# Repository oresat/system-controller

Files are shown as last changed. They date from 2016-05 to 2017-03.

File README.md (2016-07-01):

# OreSat "System controller" Board
<p align="center">
  
</p>
## Overview

The System Controller (SC) is part of the sputnik capstone project and is a robust module that is a vital piece of the avionics stack for the cubesat. It is tasked with performing the most critical job of all: monitoring the well-being of the stack and power cycling modules when [Single-Event Upsets](https://en.wikipedia.org/wiki/Single_event_upset) happen. At the heart of the module will be a radiation hardened microcontroller that communicates with the Low Gain Radio and Payload via UART. There are power switches with circuit breakers ("efuses") connected to the microcontroller that allow it to control the flow of power to all of the other systems/modules on the CubeSat.  
Low level diagram of System Controller  

## Main Topics
[Parts Selection](https://github.com/oresat/system-controller/blob/master/docs/PartsSelection.md)  
[Bill of Materials](https://github.com/oresat/system-controller/blob/master/docs/BOM_SC.xls)  
[Eagle Schematic](https://github.com/oresat/system-controller/blob/master/eagle/system-controller.sch)    
[Eagle Layout](https://github.com/oresat/system-controller/blob/master/eagle/system-controller.brd)    
[Test Plan](https://github.com/oresat/low-gain-radio/blob/master/docs/Test_Plan_Sputnik_Capstone.md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)   

## Contents

datasheets - datasheets for components used

docs - documentation

eagle - contains Schematic and PCB layout for the System Controller

firmware - contains firmware for the System Controller and tools for compiling/debugging

## Project team

Industry Sponsor: Andrew Greenberg (adg@ece.pdx.edu)

Faculty Advisor: Dr. Christof Teuscher (teuscher@pdx.edu)

* Capstone Team

    * William Harrington (wrh2@pdx.edu)

    * Shan Quinney (quinney@pdx.edu)

    * Jake Heath (jakeheath@gmail.com)

    * Mike Mathis (mdmathis@gmail.com)

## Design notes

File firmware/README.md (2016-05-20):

# System Controller Firmware

This folder contains the firmware for the system controller.
The system controller contains an [Atmega128](http://www.atmel.com/devices/ATMEGA128.aspx) which is a microcontroller developed by [Atmel](http://www.atmel.com/).
The microcontroller itself is composed of an [AVR based architecture](https://en.wikipedia.org/wiki/Atmel_AVR) which was developed by Atmel.
It is for this reason that the tool chain for the system controller and low gain radio are completely different.
Furthermore, the Atmega128 is not going to be used for actual flight/deployment in space. Instead, there is a [radiation-hardened version](http://www.atmel.com/devices/ATmegaS128.aspx) of it that we plan to use.
As far as programming is concerned, there is no difference between this version and the Atmega128.

## Dependencies

[avrdude](http://www.nongnu.org/avrdude/)

## Caveats

The Makefile assumes an Atmel AVR JTAGICE3 is being used with an Atmega128.

## Fuse bits

In order for the clock to function properly the currect fuse bits need to be set. This can be done in avrdude by including the following command line argument:

	-U lfuse:w:0xc0:m -U hfuse:w:0x89:m -U efuse:w:0xff:m

The CKOPT bit is set so that the crystal receives more power so that it can be detected reliably at 8MHz. If CKOPT is not set, the clock from the crystal wont be strong enough.

## Example usage

* To compile

    > make

* To complie and write to Atmega128

    > make load

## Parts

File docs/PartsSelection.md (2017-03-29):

# Parts Selection for System Controller
**Table of Contents**	
* [Microcontroller](https://github.com/oresat/system-controller/blob/master/docs/PartsSelection.md#u1-atmel-atmega128)	
* [LDO](https://github.com/oresat/system-controller/blob/master/docs/PartsSelection.md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)	
* [Optical Isolator](https://github.com/oresat/system-controller/blob/master/docs/PartsSelection.md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)		
* [Power Management (eFuse)](https://github.com/oresat/system-controller/blob/master/docs/PartsSelection.md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) 	
* [8:1 Multiplexer](https://github.com/oresat/system-controller/blob/master/docs/PartsSelection.md#u15-silicon-labs-ts4100itq1633)		
* [SuperCap](https://github.com/oresat/system-controller/blob/master/docs/PartsSelection.md#c1-elna-america-dsk-3r3h224u-hl) 	
* [Schottky Diode](https://github.com/oresat/system-controller/blob/master/docs/PartsSelection.md#d1-d2-d3-vishay-ssc53l-e357t)		
* [8MHz Crystal](https://github.com/oresat/system-controller/blob/master/docs/PartsSelection.md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)		
* [MOSFETs](https://github.com/oresat/system-controller/blob/master/docs/PartsSelection.md#mosfets)		
* [Connectors](https://github.com/oresat/system-controller/blob/master/docs/PartsSelection.md#connectors)				
* [LEDs](https://github.com/oresat/system-controller/blob/master/docs/PartsSelection.md#leds)	
* [Capacitors](https://github.com/oresat/system-controller/blob/master/docs/PartsSelection.md#capacitors)	
* [Resistors](https://github.com/oresat/system-controller/blob/master/docs/PartsSelection.md#resistors)

Format note  

#### Format note  
Eagle Reference, Manufacturer, Manufacturer's Part Number  
Vendor  
Vendor Part No  
Datasheet  
Reasons  
Rad-hard Analogue 

#### U1 Atmel ATMega128  
Description: Microcontroller 8BIT 128KB FLASH 	
Vendor: Digi-Key 	
Vendor Part No.: ATMEGA128L-8AU 			
[Datasheet](http://www.atmel.com/images/doc2467.pdf)  
Reasons: The ATMega128 comes in both a radiation hardened and non-hardened version. This gives us the ability to fabricate and test the full board for functionality using the cheaper non-hardened version before purchasing the more expensive radiation tolerant part. An additional benefit is that the ATMega128 has a large community of users with access to open source code and documentation. This will help us bring the chip up quickly.
Rad-hard Analogue: ATmegaS128		
[Datasheet](http://aerosupport.atmel.com/Atmel/doc41036.pdf)  

#### U2 Texas Instruments LP5907MFX-3.0/NOPB 
Description:  MCU LDO  
Vendor: Digi-Key  
Vendor Part No.: 296-40357-1-ND		
[Datasheet](http://www.ti.com/lit/ds/symlink/lp5907.pdf)  
Reasons: This is a replacement for our original choice - the Skyworks AAT3215, which is not available through digikey. This one comes in the same package and it also has a functionally equivalent pin-out to the AAT3215. The input voltage range is 2.2V to 5.5 V and the drop out voltage is given at 120 mV.	
Rad-Hard Analogue: ISL75051SEH	
[Datasheet](http://www.intersil.com/content/dam/Intersil/documents/isl7/isl75051seh.pdf)	
Reasons: This chip is rated with a low drop out of 65mV at 1A (225mV at 3A). The IC operates over a voltage range of 2.2V to 6.0V and can provide output voltages between 0.8V and 5V. The output voltage is set using an external resistive voltage divider.

#### U3, U4, U5, U6 Broadcom Limited ACPL-M61L-000E
Description: Optoisolator 3.75KV PUSH PULL 	
Vendor: Digi-Key  
Vendor Part No.: 516-2169-5-ND		
[Datasheet](http://www.avagotech.com/docs/AV02-2150EN)  
Reasons: This IC is less complex than other comparable products. The chip can be powered from a 3.0V supply and features a low 1.6mA input current. The temperature range exceeds requirements on the high end (-40C to 105C). As a note, the output is inverted.		
Rad-hard Analogue: Avago HCPL5431		
[Datasheet](http://www.avagotech.com/docs/AV02-3838EN)

#### U7, U8, U9, U10, U11, U12, U13, U14 Texas Instruments TPS25944LRVCR
Description: IC Power Management eFuse 		
Vendor: Digi-Key  
Vendor Part No.: 296-42152-1-ND		
[Datasheet](http://www.ti.com/lit/ds/symlink/tps25944a.pdf)		
Reasons: This IC offered the most complete solution compared to the competition. The chip can be powered from a 3.0V supply (has an operating voltage range of 2.7V to 18V). It has a current limiting feature, which is set by an external resistor. It alows for current monitoring, undervoltage protection, overvoltage protection, and the slew rate is adjustable by use of an external capacitor.		
Rad-hard Analogue: Intersil ISL706		
[Datasheet](https://www.intersil.com/content/dam/Intersil/documents/isl7/isl705arh-05brh-05crh-05aeh-05beh-05ceh-06arh-06brh-06crh-06aeh-06beh-06ceh.pdf)

#### U15 Silicon Labs TS4100ITQ1633
Description: 8:1 Mux	/ Analog Switch
Vendor: Digi-Key  
Vendor Part No.: 336-3600-ND	
[Datasheet](http://www.silabs.com/Support%20Documents/TechnicalDocs/TS410x.pdf)		
Reasons: This chip could be considered generic as there were no specific reasons that it was chosen other than it can be powered from 3.0V and comes in a small 3 x 3 TQFN package.			
Rad-hard Analogue: ST M54HC4051		
[Datasheet](http://www2.st.com/content/ccc/resource/technical/document/datasheet/20/18/fe/5f/87/91/46/35/CD00270015.pdf/files/CD00270015.pdf/jcr:content/translations/en.CD002700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)

#### C1 Elna America DSK-3R3H224U-HL
Description: 220 mF SuperCap	
Vendor: Digi-Key  
Vendor Part No.: 604-1020-1-ND		
[Datasheet](http://media.digikey.com/pdf/Data%20Sheets/Elna%20America%20Inc/DS,DSK.pdf)		
Reasons:  The same capacitor was used on a previous PSAS board and proved to be reliable. This capacitor should supply at least half a minute of charge if the power system fails.	 
Rad-hard Analogue: N/A

#### D1, D2, D3 Vishay SSC53L-E3/57T
Description: Schottky Diode	
Vendor: Digi-Key  		
Vendor Part No.: SSC53L-E3/57TGICT-ND	
[Datasheet](https://www.vishay.com/docs/88885/ssc53l.pdf)	
Reasons: This Diode was chosen because it has a similar turn-on voltage to the radiation hardened version.	
Rad-Hard Analogue: ST 1N5819U:		
[Datasheet](http://www.st.com/st-web-ui/static/active/en/resource/technical/document/datasheet/CD00241480.pdf)		
Reasons: Low Turn-on voltage. 

#### X1 Abaracon LLC ABM3-8.000MHZ-D2Y-T 
Description:  8MHz +/- 20ppm Crystal    
Vendor: Digi-Key  
Vendor Part No.: 1535-10630-1-ND	
[Datasheet](http://www.abracon.com/Resonators/abm3.pdf)  
Reasons: This is a good valued crystal with decent ppm count (+/-20ppm).	
Rad-hard Analogue: Swept Crystal		
[Datasheet](http://statek.com/products/pdf/SWCX1%20Swept%20Crystal%20Rev%20B.pdf)	
Reasons: The swept crystal is recommended for harsh environments. 

#### MOSFETs
**Q3 Didoes Inc. DMN62D0U-13**		
Description: MOSFET N-CH 60V 0.38A		
Vendor: Digi-Key  
Vendor Part No.: DMN62D0U-13DICT-ND		
[Datasheet](http://www.diodes.com/_files/datasheets/DMN62D0U.pdf)	
Reasons: This MOSFET was chosen based on the threshold voltage range of 0.5V to 1V. This allows the capacitor in the hardware watchdog circuitry more time to discharge from the 3V rail to where the FET turns off. Note: It has been dificult to find a radiation hardened transistor with a similar threshhold voltage range. This could be critical to reproducing the watchdog timing.				
Rad-Hard Option: Intentional Rectifier IRHLUB770Z4	
[Datasheet](http://www.irf.com/product-info/datasheets/data/irhlub770z4.pdf) 		
Reasons: Lowest Threshold voltage of any rad-hard FET viewed. This one is between 1V and 2V.

**Q9, Q11 On Semi. DMN62D0U-13** 
Description: MOSFET P-CH 20V 3.2A SOT23		
Vendor: Digi-Key  
Vendor Part No.: NTR4101PT1HOSCT-ND		
[Datasheet](http://www.onsemi.com/pub_link/Collateral/NTR4101P-D.PDF)	
Reasons: Generic P-channel MOSFET. 	
Rad-hard Analogue: International Rectifier IRHYB597Z30CM	
[Datasheet](http://www.irf.com/product-info/datasheets/data/irhyb597z30cm.pdf)		
Reasons: This transistor should be considered generic.

**Q1, Q2, Q4, Q5, Q6, Q7, Q8, Q10 Diodes Inc. DMG6601LVT-7**     
Description: MOSFET, N/P pair     
Vendor: Digi-Key  
Vendor Part No.: DMG6601LVT-7DICT-ND 	  
[Datasheet](http://www.diodes.com/_files/datasheets/DMG6601LVT.pdf)  
Reasons: This chip has been used in a previous PSAS design and has proved to be reliable.	
Rad-hard Analogue: International Rectifier IRHLUC7670Z4			
[Datasheet](http://www.irf.com/product-info/datasheets/data/irhluc7670z4.pdf)
Reasons: This chip should be considered generic.

#### Connectors
**J1 CNC Tech 3220-10-0100-00** 
Description: JTAG Connector    
Vendor: Digi-Key  
Vendor Part No.: 1175-1627-ND   
[Datasheet](http://cnctech.us/pdfs/3220-XX-0100-00.pdf)  
Reasons: This is a generic JTAG connector.	
Rad-hard Analogue: N/A	

**CF1, CF2 Harwin Inc. M50-3202045**     
Description: 40-Pinout Header     
Vendor: Digi-Key  
Vendor Part No.: 952-1381-5-ND  	  
[Datasheet](https://cdn.harwin.com/pdfs/M50-320.pdf)  
Reasons: This is a design requirement for communication from the Cubesat and allows for a link between the LGR and System Controller.			
Rad-hard Analogue: N/A	

### LEDs
**LED1, LED2, LED3, LED4, LED5, LED6, LED7, LED8, LED13 Wurth Electronics, Inc. 150060GS75000**      
Description: Green LEDs    
Vendor: Digi-Key  
Vendor Part No.: 732-4971-1-ND 	
[Datasheet](http://katalog.we-online.de/led/datasheet/150060GS75000.pdf)  
Reasons: LED1 - LED8 are on the VCB0 - VCB7 lines and are functionally located between the output of the eFuse modules and the input of the 40 pin connector. LED13 is used to indicate 3.0V operation. They are placed at the front of the board for easy viewing and when on represent that the line of interest is working. These LEDs are for debugging only and will be removed before launch.			
Rad-hard Analogue: N/A	

**LED9, LED10, LED11, LED12 OSRAM Optp Semi. LA L296-Q2R2-1-Z**      
Description: Amber LEDs    
Vendor: Digi-Key  
Vendor Part No.: 475-2712-1-ND  
[Datasheet](http://media.digikey.com/pdf/Data%20Sheets/Osram%20PDFs/LS,LA,LO,LY_296.pdf)  
Reasons: Amber LEDs are used for error checks during debugging and are placed on the debugging lines for UART. They will also be removed before actual launch.	
Rad-hard Analogue: N/A	

### Capacitors

**C1, C6, C7, C9, C14, C20, C22, C23, C25, C29 Samsung CL10B105KP8NNNC**       
Description: 1µF ±10% 10V X7R Ceramic Capacitor SMD, MLCC 0603 
Vendor: Digi-Key  
Vendor Part No.: 1276-1946-1-ND  
[Datasheet](http://www.samsungsem.com/kr/support/product-search/mlcc/__icsFiles/afieldfile/2015/06/15/CL10B105KP8NNNC.pdf)  
Reasons: These capacitors are used as bypass caps. C1, C7, C9, C14, C20, C22, C25, and C29 are used on the eFuse ICs. C23 is found on the 8:1 Mux and C6 is on the LDO.	
Rad-hard Analogue: N/A	

**C2, C8, C11, C16, C21, C24, C26, C30 Samsung CL10C222GA8NNNC**       
Description: 2200pF ±2% 25V C0G, NP0 Ceramic Capacitor SMD, MLCC 0603
Vendor: Digi-Key  
Vendor Part No.: 1276-2239-1-ND		
[Datasheet](http://www.samsungsem.com/kr/support/product-search/mlcc/__icsFiles/afieldfile/2015/06/03/CL10C222GA8NNNC.pdf)  
Reasons: C2, C8, C11, C16, C21, C24, C26, and C30 are used on the TPS25944LRVCR eFuse IC's to set the ramp rate of output voltage.	
Rad-hard Analogue: N/A	

**C15, C17 Samsung CL10C090DB8NNNC**       
Description: 9pF ±0.5pF 50V C0G, NP0 Ceramic Capacitor SMD, MLCC 0603	
Vendor: Digi-Key  
Vendor Part No.: 1276-2143-1-ND		
[Datasheet](http://www.samsungsem.com/kr/support/product-search/mlcc/__icsFiles/afieldfile/2015/06/03/CL10C090DB8NNNC.pdf)  
Reasons: These caps compliment the 8MHz Crystal on the ATMega128 microcontroller.	
Rad-hard Analogue: N/A	

**C5 Samsung CL10A225KQ8NNNC**       
Description: 2.2µF ±10% 6.3V X5R Ceramic Capacitor SMD, MLCC 0603	
Vendor: Digi-Key  
Vendor Part No.: 1276-1183-1-ND		
[Datasheet](http://www.samsungsem.com/kr/support/product-search/mlcc/__icsFiles/afieldfile/2015/08/14/S_CL10A225KQ8NNNC.pdf)  
Reasons: C5 is used as a bypass capacitor on the LDO. 	
Rad-hard Analogue: N/A	

**C10 Samsung CL10A226KQ8NRNE**       
Description: 22µF ±10% 6.3V X5R Ceramic Capacitor SMD, MLCC 0603	
Vendor: Digi-Key  
Vendor Part No.: 1276-2867-2-ND		
[Datasheet](http://media.digikey.com/pdf/Data%20Sheets/Samsung%20PDFs/CL10A226KQ8NRNE_Spec.pdf)  
Reasons: This capacitor is used on the Hardware Watchdog as part of the RC timing circuit.	 
Rad-hard Analogue: N/A	

**C4 Kemet C0603C103J5RACTU**       
Description: 10000pF ±5% 50V X7R Ceramic Capacitor SMD, MLCC 0603	
Vendor: Digi-Key  
Vendor Part No.: 399-1092-1-ND	
[Datasheet](http://www.kemet.com/docfinder?Partnumber=C0603C103J5RACTU)  
Reasons: C4 is used as a bypass Cap on the AAT3215 LDO.	It is not used on the current LDO as that pin is a no connect.	
Rad-hard Analogue: N/A

**C12, C13, C18, C19, C27, C28, C31, C32 Kemet C0603C103J5RACTU**       
Description: 0.10µF ±5% 16V X7R Ceramic Capacitor SMD, MLCC 0603	
Vendor: Digi-Key  
Vendor Part No.: 399-1097-1-ND	
[Datasheet](http://www.kemet.com/Lists/ProductCatalog/Attachments/53/KEM_C1002_X7R_SMD.pdf)  
Reasons: C12, C13, C18, and C19 are used as bypass caps on the ATMega128 microcontroller. C27, C28, C31, and C32 are used as bypass caps on the optoisolators.	
Rad-hard Analogue: N/A	
#### Resistors

**R7	Samsung	RC1608F103CS**      
Description: RES SMD 10K OHM 1% 1/10W 0603				
Vendor: Digi-Key				  
Vendor Part No.: 1276-3485-1-N				 	
[Datasheet](http://media.digikey.com/pdf/Data%20Sheets/Samsung%20PDFs/RC_Series_ds.pdf)  
Reasons: This 10k resistor is used as a pull-up resistor on the LDO.		
Rad-hard Analogue: N/A	    

**RIMON1, RIMON2, RIMON3, RIMON4, RIMON5, RIMON6, RIMON7, RIMON8 Samsung RC1608F3012CS**      
Description: RES SMD 30.1K OHM 1% 1/10W 0603				
Vendor: Digi-Key			  
Vendor Part No.: 1276-4787-1-N				 	
[Datasheet](http://media.digikey.com/pdf/Data%20Sheets/Samsung%20PDFs/RC_Series_ds.pdf)  
Reasons: These resistors are configured as current monitoring resistors for the eFuse circuitry. They allow the microcontroller to monitor the amount of current through the output of each eFuse IC.	
Rad-hard Analogue: N/A	

**R18 Samsung RC1608F474CS**      
Description: RES SMD 470K OHM 1% 1/10W 0603				
Vendor: Digi-Key			  
Vendor Part No.: 1276-4902-1-ND 				 
[Datasheet](http://media.digikey.com/pdf/Data%20Sheets/Samsung%20PDFs/RC_Series_ds.pdf)  
Reasons: This resistor is part of the RC timing circuit in the hardware watchdog. It compliments capacitor C10 for this purpose.
Rad-hard Analogue: N/A	

**R14, R15, R16, R19, R25, R54, R60, R61, R70, R72, R74  Samsung RC0603FR-071KL**      
Description: RES SMD 390 OHM 0.1% 1/16W 060			   
Vendor: Digi-Key				  
Vendor Part No.: 1276-4610-1-N				 	
[Datasheet](http://media.digikey.com/pdf/Data%20Sheets/Samsung%20PDFs/RC_Series_ds.pdf)  
Reasons: R25 is used as a pull-up resistor for the !RESET line on the ATMega128. R54, R61, R70, and R74 are used as pull-up resistors on the Optoisolators. R60 and R72 are on the output lines of the optoisolators and act as pull down resistors when the output is low. RN14, RN15, RN16, and RN19 are used as part of the hardware watchdog voltage divide network. 	
Rad-hard Analogue: N/A	

**R4, R11, R22, R29, R43, R49, R57, R67 Yageo RC1608F472CS**     
Description: RES SMD 4.7K OHM 1% 1/10W 060				 
Vendor: Digi-Key				  
Vendor Part No.: 1276-3502-1-N				 	
[Datasheet](http://media.digikey.com/pdf/Data%20Sheets/Samsung%20PDFs/RC_Series_ds.pdf)  
Reasons: These resistors are part of the external biasing of the eFuse section P/N MOSFET network.	
Rad-hard Analogue: N/A	

**R2, R9, R20, R27, R41, R47, R55, R65 Samsung RC1608F9312CS**      
Description: RES SMD 93.1K OHM 1% 1/10W 060			 
Vendor: Digi-Key				  
Vendor Part No.: 1276-4837-1-ND 				 
[Datasheet](http://media.digikey.com/pdf/Data%20Sheets/Samsung%20PDFs/RC_Series_ds.pdf)  
Reasons: Used as under voltage lock out for the eFuse IC's. This is part of a voltage divider network that sets the voltage at the EN/UVLO pin to 3V.	
Rad-hard Analogue: N/A	

**R3, R10, R21, R28, R42, R48, R52, R56, R63, R66, R71, R75, R76 Samsung RC1608F102CS**      
Description: RES SMD 1K OHM 1% 1/10W 0603		
Vendor: Digi-Key		 
Vendor Part No.: 1276-3484-1-ND				
[Datasheet](http://media.digikey.com/pdf/Data%20Sheets/Samsung%20PDFs/RC_Series_ds.pdf)  
Reasons:  R52, R63, R71, and R75 are used as current limiting resistors on the Amber LEDs. R3, R10, R21, R28, R42, R48, R56, R66, and R76 are used as current limiting resistors on the Green LEDs.	
Rad-hard Analogue: N/A	

**R1, R5, R6, R8, R12, R13, R17, R23, R24, R26, R30, R31, R32, R33, R34, R35, R36, R37, R38, R39, R40, R44, R45, R46, R50, R51, R53, R58, R59, R62, R64, R68, R69, R73, RILIM1, RILIM2, RILIM3, RILIM4, RILIM5, RILIM6, RILIM7, RILIM8 Samsung RC1608F473CS**      
Description: RES SMD 47K OHM 1% 1/10W 0603		
Vendor: Digi-Key		 
Vendor Part No.: 1276-4808-1-ND 			
[Datasheet](http://media.digikey.com/pdf/Data%20Sheets/Samsung%20PDFs/RC_Series_ds.pdf)  
Reasons: R5, R12, R23, R30, R44, R50, R58, and R68 are part of the voltage divider network that sets the UVLO voltage on the eFues. R1, R5, R8, R12, R17, R23, R26, R30, R40, R44, R46, R50, R53, and R64 are used as part of the bias on the eFuse P/N MOSFET network. R32, R33, R34, R35, R36, R37, R38, R39 are used as pull up resistors on the VCB0-VCB7_FLT lines. RILIM0, RILIM1, RILIM2, RILIM3, RILIM4, RILIM5, RILIM6, RILIM7 are used to limit the current through the eFuse to 1.9A.	
Rad-hard Analogue: N/A

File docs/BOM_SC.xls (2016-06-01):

Bill Of Materials for PSAS System Controller (SC)
source file: system-controller.sch
Variant: NA
PCB version 1.0
BOM revision 0 |  |  | P/DNP = | Place/Do Not Place (DNP is for final production boards)
Last Modified: 2016.04.14 |  |  | Generic = | Any generic part with the same characteristics are OK (e.g., bypass cap)
Cnt | Part References | Manf | PN | P/DNP | Desc | Vendor | Vendor-PN | Generic | Price/Part | Extended
1 | J1 | CNC Tech | 3220-10-0100-00 |  | JTAG PIN HEADER 2x5 This is one of the (smaller) ARM standard JTAG connectors. | digikey | 1175-1627-ND | Y | 0.48 | 2.4
8 | C12, C13, C18, C19, C27, C28, C31, C32 | Kemet | C0603C104J4RACTU |  | 0.10µF ±5% 16V X7R Ceramic Capacitor SMD, MLCC 0603 | digikey | 399-1097-1-ND | Y | 0.0432 | 2.16
1 | R7 | Samsung | RC1608F103CS |  | RES SMD 10K OHM 1% 1/10W 0603 | digikey | 1276-3485-1-ND | Y | 0.014 | 0.14
1 | C4 | Kemet | C0603C103J5RACTU |  | 10000pF ±5% 50V X7R Ceramic Capacitor SMD, MLCC 0603 | digikey | 399-1092-1-ND | Y | 0.036 | 0.36
10 | C1, C6, C7, C9, C14, C20, C22, C23, C25, C29 | Samsung | CL10B105KP8NNNC |  | 1µF ±10% 10V X7R Ceramic Capacitor SMD, MLCC 0603 | digikey | 1276-1946-1-ND | Y | 0.0222 | 1.11
8 | C2, C8, C11, C16, C21, C24, C26, C30 | Samaung | CL10C222GA8NNNC |  | 2200pF ±2% 25V C0G, NP0 Ceramic Capacitor SMD, MLCC 0603 | digikey | 1276-2239-1-ND | Y | 0.0806 | 4.03
1 | C5 | Samsung | CL10A225KQ8NNNC |  | 2.2µF ±10% 6.3V X5R Ceramic Capacitor SMD, MLCC 0603 | digikey | 1276-1183-1-ND | Y | 0.087 | 0.87
1 | C10 | Kemet | CL10A226KQ8NRNE |  | 22µF ±10% 6.3V X5R Ceramic Capacitor SMD, MLCC 0603 | digikey | 1276-2867-2-ND | Y | 0.288 | 2.88
8 | RIMON0, RIMON1, RIMON2, RIMON3, RIMON4, RIMON5, RIMON6, RIMON7 | Samsung | RC1608F3012CS |  | RES SMD 30.1K OHM 1% 1/10W 0603 | digikey | 1276-4787-1-ND | Y | 0.0078 | 0.39
9 | R14, R15, R16, R19, R25, R54,, R61, R70, R74 | TE | RC1608F391CS |  | RES SMD 390 OHM 0.1% 1/16W 0603 | digikey | 1276-4610-1-ND | Y | 0.0078 | 0.39
8 | R4, R11, R22, R29, R43, R49, R57, R67 | Samsung | RC1608F472CS |  | RES SMD 4.7K OHM 1% 1/10W 0603 | digikey | 1276-3502-1-ND | Y | 0.0078 | 0.39
1 | R18 | Samsung | RC1608F474CS |  | RES SMD 470K OHM 1% 1/10W 0603 | digikey | 1276-4902-1-ND | Y | 0.014 | 0.14
42 | R1, R5, R6, R8, R12, R13, R17, R23, R24, R26, R30, R31, R32, R33, R34, R35, R36, R37, R38, R39, R40, R44, R45, R46, R50, R51, R53, R58, R59, R62, R64, R68, R69, R73, RILIM1, RILIM2, RILIM3, RILIM4, RILIM5, RILIM6, RILIM7, RILIM8 | Samsung | RC1608F473CS |  | RES SMD 47K OHM 1% 1/10W 0603 | digikey | 1276-4808-1-ND | Y | 0.0057 | 1.14
1 | X1 | Abracon LLC | ABM3-8.000MHZ-D2Y-T |  | 8MHz ±20ppm Crystal 18pF 140 Ohm 2-SMD | digikey | 535-10630-1-ND | Y | 0.69 | 3.45
8 | R2, R9, R20, R27, R41, R47, R55, R65 | Samsung | 1276-4837-1-ND |  | RES SMD 93.1K OHM 1% 1/10W 0603 | digikey | 1276-4837-1-ND | Y | 0.0078 | 0.39
2 | C15, C17 | Samsung | CL10C090DB8NNNC |  | 9pF ±0.5pF 50V C0G, NP0 Ceramic Capacitor SMD, MLCC 0603 | digikey | 1276-2143-1-ND | Y | 0.037 | 0.37
1 | U2 | Texas Instruments | LP5907MFX-3.0/NOPB |  | IC REG LDO 3V 0.25A SOT23-5 | digikey | 296-40357-1-ND | Y | 0.488 | 4.88
4 | U3, U4, U5, U6 | Broadcom | ACPL-M61L-000E |  | OPTOISO 3.75KV PUSH PULL 5SO | digikey | 516-2169-5-ND | Y | 1.7228 | 43.07
1 | C1 | Elna America | DSK-3R3H224U-HL |  | CAP 220MF -20% +80% 3.3V SMD | digikey | 604-1020-1-ND | Y | 1.426 | 14.26
13 | R3, R10, R21, R28, R42, R48, R52, R56, R63, R66, R71, R75, R76 | Samsung | RC1608F102CS | DNP | RES SMD 1K OHM 1% 1/10W 0603 | digikey | 1276-3484-1-ND | Y | 0.0078 | 0.39
4 | LED8, LED9, LED10, LED11 | OSRAM Op | LA L296-Q2R2-1-Z | DNP | LED AMBER DIFFUSED 0603 SMD | digikey | 475-2712-1-ND | Y | 0.083 | 1.66
8 | LED0, LED1, LED2, LED3, LED4, LED5, LED6, LED7, LED13 | Wurth Electronics | 150060GS75000 | DNP | LED GREEN CLEAR 0603 SMD | digikey | 732-4971-1-ND | Y | 0.21 | 10.5
2 | Q9, Q11 | ON Semic | NTR4101PT1H |  | MOSFET P-CH 20V 3.2A SOT23 | digikey | NTR4101PT1HOSCT-ND | Y | 0.346 | 3.46
1 | Q3 | Diodes Inc, | DMN62D0U-13 |  | MOSFET N-CH 60V 0.38A | digikey | DMN62D0U-13DICT-ND | Y | 0.255 | 2.55
1 | U1 | Atmel | ATMEGA128-16AUR |  | MICROCONTROLLER IC MCU 8BIT 128KB FLASH 64TQFP | digikey | ATMEGA128-16AURCT-ND | N | 16.05 | 80.25
8 | Q1, Q2, Q4, Q5, Q6, Q7, Q8, Q10 | Diodes Inc. | DMG6601LVT-7 |  | MOSFET N/P-CH 30V 26TSOT | digikey | DMG6601LVT-7DICT-ND | N | 0.283 | 8.49
2 | CF1, CF2 | Harwin Inc. | M50-3202045 |  | CONN RCPT 1.27MM T/H R/A 40POS (40 pin header) | digikey | 952-1381-5-ND | N | 5.126 | 51.26
3 | D1, D2, D3 | Vishay | SSC53L-E3/57T |  | DIODE SCHOTTKY 30V 5A DO214AB | digikey | SSC53L-E3/57TGICT-ND | N | 0.534 | 6.408
8 | U7, U8, U9, U10, U11, U12, U13, U14 | Texas Instruments | TPS25944LRVCR |  | IC PWR MGMT EFUSE 2.7-18V 20WQFN | digikey | 296-42152-1-ND | N | 1.843 | 55.29
1 | U15 | Silicon Labs | TS4100ITQ1633 |  | 80 RON ANALOG SWITCH/MULTIPLEXE | digikey | 336-3600-ND | N | 1.22 | 4.88
2 |  |  |  |  |  |  |  |  |  | 307.958

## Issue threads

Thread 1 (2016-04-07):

Repo description

wrh2, 2016-04-07:
Repository is in need of a description. I'd gladly give it one myself but I don't have the ability to do that for whatever reason.

ThirteenFish, 2016-05-16:
I've got the ability to put it in. If you write the text I'll get it up there.

wrh2, 2016-05-23:
Something like: "Radiation-hardened avionics module for CubeSat v1. Responsible for monitoring the well-being of the stack and power cycling modules when Single-Event Upsets happen."

natronics, 2016-05-23:
I added it. Has to be really short to fit in the header though. I only took the first sentence. Is that look okay?

wrh2, 2016-05-23:
Looks good. Thanks, Nate.

Closed 2016-05-23.

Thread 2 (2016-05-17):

Remove 390 Ohm resistor R60 and R70 on V2 board

shanodean, 2016-05-17:
These were left in by mistake when the optoisolator circuitry was redesigned for the inverting output. They are not hurting anything but are not helpful either.

Bearking, 2016-07-07:
These are left as 0 ohm resistors at the moment. I'm gonna consider this closed unless otherwise noted.

Closed 2016-07-07.

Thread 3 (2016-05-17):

Remove C4 from the 3.0V LDO on future builds

shanodean, 2016-05-17:
The replacement LDO (LP5907MFX-3.0) has a NC on pin 4. This was not updated in the schematic so the 10nF bypass cap is useless. This needs to be updated on V2 board.

Bearking, 2016-07-07:
Removed from schematic/board

Closed 2016-07-07.

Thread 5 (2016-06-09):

The schottky diode used in the analog watchdog needs replaced

shanodean, 2016-06-09:
We need to replace the schottky diode that is used in the analog watchdog. It has a turn on voltage that is below what was calculated due to the low bias current. The circuit was designed so that the turn on voltage was about 450mV and it is actually closer to 100mV. Because of this, the watchdog activates the FET when only one flag is raised. The recommendation is to swap out this diode for a regular p/n diode which will have a turn on voltage closer to 0.7V.

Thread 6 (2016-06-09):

JTAG pin connector

shanodean, 2016-06-09:
The JTAG connector on the SC board is configured wrong and should be updated on the next board rev.

Bearking, 2016-07-07:
Fixed this for the next rev.

Closed 2016-07-07.

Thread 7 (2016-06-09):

1k resistors on the optical isolator ICs should be changed

shanodean, 2016-06-09:
It is recommended to lower the resistance of the 1kOhm resistors used on the output of the optoisolator chips for UART lines TXD0 and TXD1. Currently these have been replaced with 0 Ohm resistors.

Bearking, 2016-07-07:
This has already been changed in the schematic for next rev

Closed 2016-07-07.

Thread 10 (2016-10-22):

Add RTD/thermocouple - digitial temperature measurement capability to system controller

kwilsonpdx, 2016-10-22:
Temperature management of the cubesat airframe and avionics implies a requirement to have an ability to monitor temperature during development, testing and possibly flight.

The system controller board appears the likely candidate to add a temperature measurement IC which could monitor RTDs or Theromocouples (Type K or Type E (vacuum)? TBD).

* The system controller board has the capacity to react to temperature events.
* There is an open SPI connection on the ATMEGA128L on the current design.
* There is space available on the board layout.

Here is an example IC for reference:

https://cds.linear.com/docs/en/datasheet/2984fb.pdf

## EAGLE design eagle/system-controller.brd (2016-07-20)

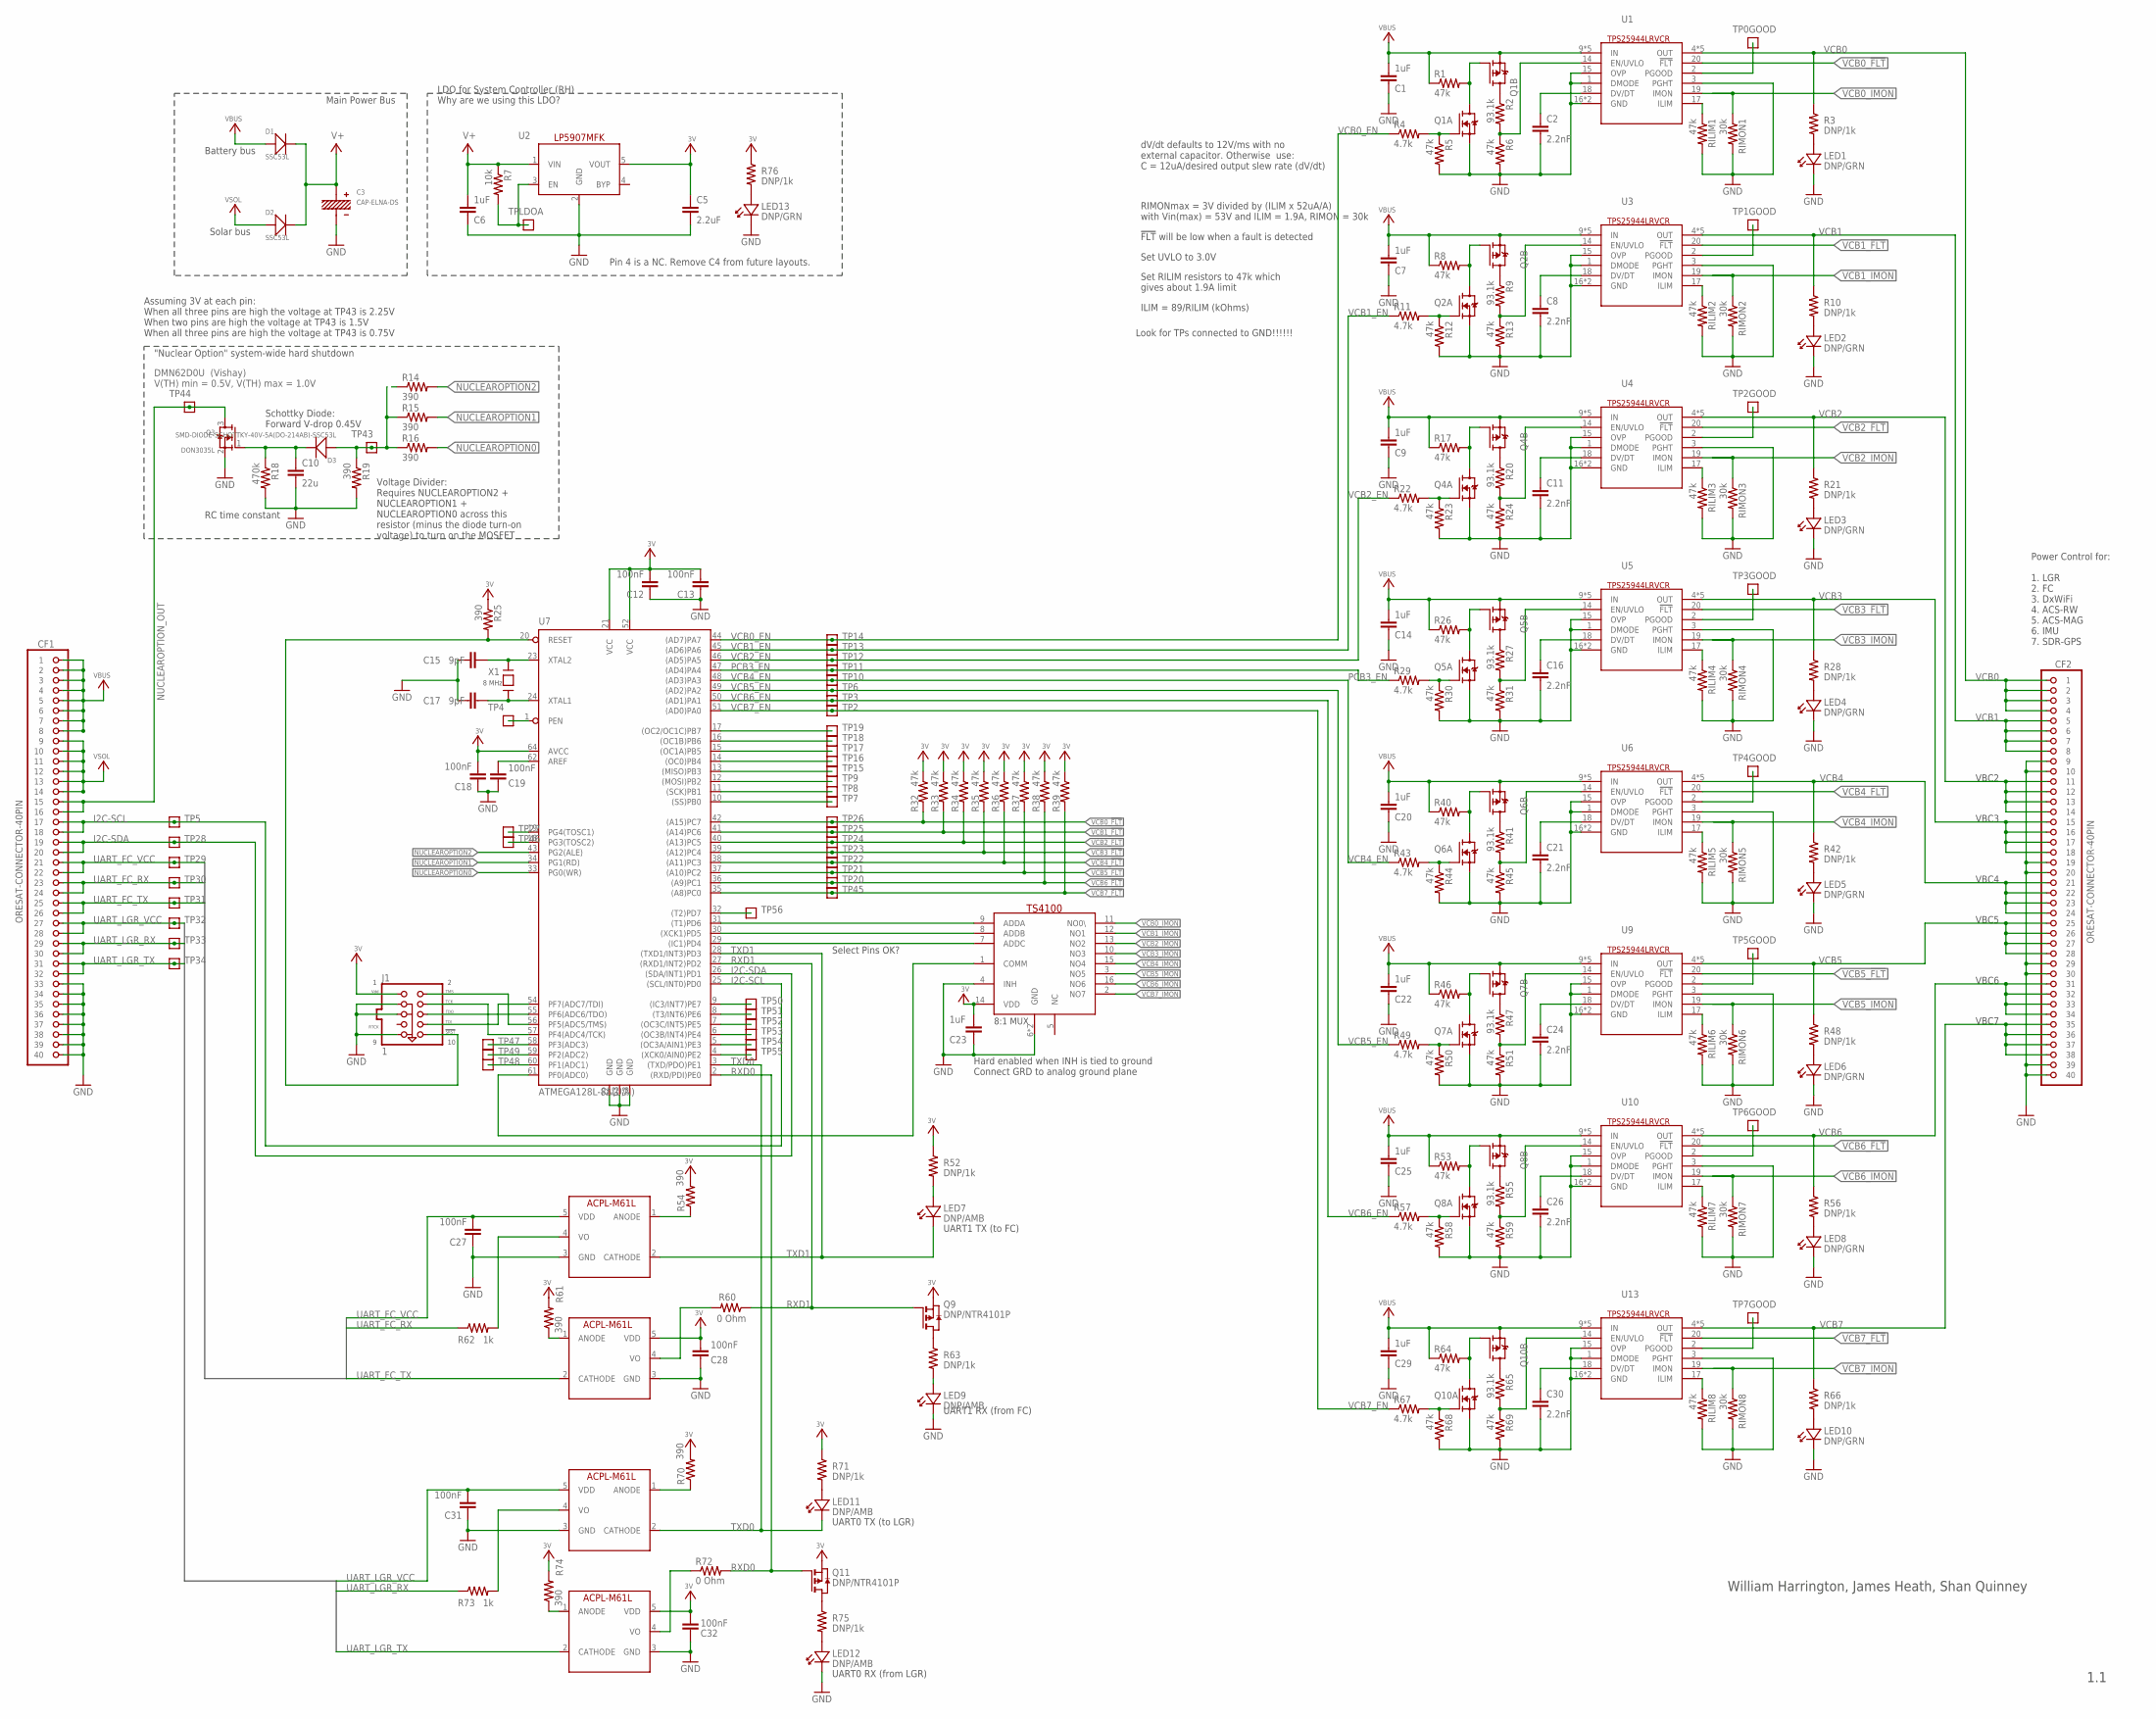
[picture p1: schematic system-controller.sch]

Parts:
C1, C6, C7, C9, C14, C20, C22, C23, C25, C29: 1uF; .0603-B-NOSILK; MPN CL10B105KP8NNNC
C2, C8, C11, C16, C21, C24, C26, C30: 2.2nF; .0603-B-NOSILK; MPN CL10C222GA8NNNC
C3: CAP-ELNA-DS; CAP-ELNA-DS-SERIES; MPN DSK-3R3H224U-HL
C5: 2.2uF; .0603-B-NOSILK; MPN CL10A225KQ8NNNC
C10: 22u; .0603-B-NOSILK; MPN C0603C103J5RACTU
C12, C13, C18, C19, C27, C28: 100nF; .0603-B-NOSILK; MPN C0603C104J4RACTU
C15, C17: 9pF; .0603-B-NOSILK; MPN CBR02C909B5GAC
C31, C32: 100nF; .0603-B-NOSILK; MPN GRM155R71C104JA88D
CF1, CF2: ORESAT-CONNECTOR-40PIN; HARWIN-ARCHER-M50-3202045; MPN M50-3202045
D1, D2: SSC53L; DO-214AB; MPN SSC53L-E3/57T
D3: SMD-DIODE-SCHOTTKY-40V-5A(DO-214AB)-SSC53L; DO-214AB; MPN SSC53L-E3/57T
J1: 1; PINHEADER-2X5-0.05+POL+SILK; MPN 3220-10-0100-00
LED1, LED2, LED3, LED4, LED5, LED6, LED8, LED10, LED13: DNP/GRN; LED-0603; MPN 150060GS75000
LED7, LED9, LED11, LED12: DNP/AMB; LED-0603; MPN LA L296-Q2R2-1-Z
Q1, Q2, Q4, Q5, Q6, Q7, Q8, Q10: MOSFET-P-N-PAIR; SOT23-6; MPN DMG6601LVT-7
Q3: DON3035L; SOT23; MPN DMN62D0U-13
Q9, Q11: DNP/NTR4101P; SOT23; MPN NTR4101PT1H
R1, R5, R6, R8, R12, R13, R17, R23, R24, R26, R30, R31, R32, R33, R34, R35, R36, R37, R38, R39, R40, R44, R45, R46, R50, R51, R53, R58, R59, R64, R68, R69: 47k; .0603-B-NOSILK; MPN RC1608F473CS
R2, R9, R20, R27, R41, R47, R55, R65: 93.1k; .0603-B-NOSILK; MPN RC1608F9312CS
R3, R10, R21, R28, R42, R48, R52, R56, R63, R66, R71, R75, R76: DNP/1k; .0603-B-NOSILK; MPN RC1608F102CS
R4, R11, R22, R29, R43, R49, R57, R67: 4.7k; .0603-B-NOSILK; MPN RC1608F472CS
R7: 10k; .0603-B-NOSILK; MPN RC1608F103CS
R14, R15, R16, R19, R25, R54, R61, R70, R74: 390; .0603-B-NOSILK; MPN 4-1676481-5
R18: 470k; .0603-B-NOSILK; MPN RC1608F474CS
R60, R72: 0 Ohm; .0603-B-NOSILK; MPN 4-1676481-5
R62, R73: 1k; .0603-B-NOSILK; MPN 4-1676481-5
RILIM1, RILIM2, RILIM3, RILIM4, RILIM5, RILIM6, RILIM7, RILIM8: 47k; .0603-B-NOSILK; MPN RC1608F473CS
RIMON1, RIMON2, RIMON3, RIMON4, RIMON5, RIMON6, RIMON7, RIMON8: 30k; .0603-B-NOSILK; MPN RC1608F3012CS
TP0GOOD, TP1GOOD, TP2, TP2GOOD, TP3, TP3GOOD, TP4, TP4GOOD, TP5, TP5GOOD, TP6, TP6GOOD, TP7, TP7GOOD, TP8, TP9, TP10, TP11, TP12, TP13, TP14, TP15, TP16, TP17, TP18, TP19, TP20, TP21, TP22, TP23, TP24, TP25, TP26, TP27, TP28, TP29, TP30, TP31, TP32, TP33, TP34, TP43, TP44, TP45, TP46, TP47, TP48, TP49, TP50, TP51, TP52, TP53, TP54, TP55, TP56: TEST-POINT; 2MM-TEST-POINT
TPLDOA: TEST-POINT; 2MM-TEST-POINT
U1, U3, U4, U5, U6, U9, U10, U13: TPS25944LRVCRWQFN-20-3X4; QFN-20-L; MPN TPS25944LRVCR
U2: LP5907MFX-3.0; SOT-23; MPN LP5907MFX-3.0/NOPB
U7: ATMEGA128L-8A(U/N); TQFP64
U8: TS4100; QFN50P400X400X80-17N; MPN TS4100ITQ1633
U$1, U$2, U$3, U$4: ACPL-M61L
X1: 8 MHz CRYSTAL-ABRACON-ABM3-SMD; CRYSTAL-ABRACON-ABM3-SMD; MPN Abracon LLC

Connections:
3V: C5.1, C12.2, C13.2, C18.2, C23.2, C28.2, C32.2, J1.1 (VDD), Q9.2 (S), Q11.2 (S), R25.1, R32.1, R33.1, R34.1, R35.1, R36.1, R37.1, R38.1, R39.1, R52.1, R54.2, R61.2, R70.2, R71.1, R74.2, R76.1, U2.5 (VOUT), U7.21 (VCC), U7.52 (VCC), U7.64 (AVCC), U8.14 (VDD), U$3.5 (VDD), U$4.5 (VDD)
AREF: C19.2, U7.62 (AREF)
GND: C1.1, C2.2, C3.-, C5.2, C6.1, C7.1, C8.2, C9.1, C10.2, C11.2, C12.1, C13.1, C14.1, C15.1, C16.2, C17.1, C18.1, C19.1, C20.1, C21.2, C22.1, C23.1, C24.2, C25.1, C26.2, C27.1, C28.1, C29.1, C30.2, C31.1, C32.1, CF1.P$33 (33), CF1.P$34 (34), CF1.P$35 (35), CF1.P$36 (36), CF1.P$37 (37), CF1.P$38 (38), CF1.P$39 (39), CF1.P$40 (40), CF2.P$9 (9), CF2.P$10 (10), CF2.P$19 (19), CF2.P$20 (20), CF2.P$29 (29), CF2.P$30 (30), CF2.P$39 (39), CF2.P$40 (40), J1.3 (GND3), J1.5 (GND5), J1.9 (GND9), LED1.K, LED2.K, LED3.K, LED4.K, LED5.K, LED6.K, LED8.K, LED9.K, LED10.K, LED12.K, LED13.K, Q1.5 (S), Q2.5 (S), Q3.2 (S), Q4.5 (S), Q5.5 (S), Q6.5 (S), Q7.5 (S), Q8.5 (S), Q10.5 (S), R5.2, R6.2, R12.2, R13.2, R18.2, R19.2, R23.2, R24.2, R30.2, R31.2, R44.2, R45.2, R50.2, R51.2, R58.2, R59.2, R68.2, R69.2, RILIM1.2, RILIM2.2, RILIM3.2, RILIM4.2, RILIM5.2, RILIM6.2, RILIM7.2, RILIM8.2, RIMON1.2, RIMON2.2, RIMON3.2, RIMON4.2, RIMON5.2, RIMON6.2, RIMON7.2, RIMON8.2, U1.1 (DMODE), U1.3 (PGHT), U1.15 (OVP), U1.16 (GND), U1.21 (GND), U2.2 (GND), U3.1 (DMODE), U3.3 (PGHT), U3.15 (OVP), U3.16 (GND), U3.21 (GND), U4.1 (DMODE), U4.3 (PGHT), U4.15 (OVP), U4.16 (GND), U4.21 (GND), U5.1 (DMODE), U5.3 (PGHT), U5.15 (OVP), U5.16 (GND), U5.21 (GND), U6.1 (DMODE), U6.3 (PGHT), U6.15 (OVP), U6.16 (GND), U6.21 (GND), U7.22 (GND), U7.53 (GND), U7.63 (GND), U8.4 (INH), U8.6 (GND), U8.17 (GND), U9.1 (DMODE), U9.3 (PGHT), U9.15 (OVP), U9.16 (GND), U9.21 (GND), U10.1 (DMODE), U10.3 (PGHT), U10.15 (OVP), U10.16 (GND), U10.21 (GND), U13.1 (DMODE), U13.3 (PGHT), U13.15 (OVP), U13.16 (GND), U13.21 (GND), U$1.3 (GND), U$2.3 (GND), U$3.3 (GND), U$4.3 (GND)
I2C-SCL: CF1.P$17 (17), CF1.P$18 (18), TP5.1, U7.25 ((SCL/INT0)PD0)
I2C-SDA: CF1.P$19 (19), CF1.P$20 (20), TP28.1, U7.26 ((SDA/INT1)PD1)
INOF: C2.1, U1.18 (DV/DT)
unnamed: C17.2, U7.24 (XTAL1), X1.P$2
unnamed: Q2.4 (D), R9.1
unnamed: R70.1, U$2.1 (ANODE)
unnamed: R62.2, U$1.4 (VO)
unnamed: LED13.A, R76.2
unnamed: R61.1, U$3.1 (ANODE)
unnamed: R2.2, R6.1, U1.14 (EN/UVLO)
unnamed: R20.2, R24.1, U4.14 (EN/UVLO)
unnamed: J1.4 (TCK), U7.57 (PF4(ADC4/TCK))
unnamed: J1.6 (TDO), U7.55 (PF6(ADC6/TDO))
unnamed: J1.8 (TDI), U7.54 (PF7(ADC7/TDI))
unnamed: J1.2 (TMS), U7.56 (PF5(ADC5/TMS))
unnamed: J1.10 (SRST), R25.2, U7.20 (RESET)
unnamed: R73.2, U$2.4 (VO)
unnamed: C15.2, U7.23 (XTAL2), X1.P$1
unnamed: R72.1, U$4.4 (VO)
unnamed: RILIM3.1, U4.17 (ILIM)
unnamed: RILIM1.1, U1.17 (ILIM)
unnamed: R7.2, TPLDOA.1, U2.3 (EN)
unnamed: R60.2, U$3.4 (VO)
unnamed: TP0GOOD.1, U1.2 (PGOOD)
unnamed: LED1.A, R3.2
unnamed: TP46.1, U7.18 (PG3(TOSC2))
unnamed: TP27.1, U7.19 (PG4(TOSC1))
unnamed: R9.2, R13.1, U3.14 (EN/UVLO)
unnamed: RILIM2.1, U3.17 (ILIM)
unnamed: TP1GOOD.1, U3.2 (PGOOD)
unnamed: TP4.1, U7.1 (PEN)
unnamed: TP47.1, U7.58 (PF3(ADC3))
unnamed: TP49.1, U7.59 (PF2(ADC2))
unnamed: TP48.1, U7.60 (PF1(ADC1))
unnamed: C8.1, U3.18 (DV/DT)
unnamed: TP55.1, U7.4 ((XCK0/AIN0)PE2)
unnamed: TP54.1, U7.5 ((OC3A/AIN1)PE3)
unnamed: TP53.1, U7.6 ((OC3B/INT4)PE4)
unnamed: TP52.1, U7.7 ((OC3C/INT5)PE5)
unnamed: TP51.1, U7.8 ((T3/INT6)PE6)
unnamed: TP50.1, U7.9 ((IC3/INT7)PE7)
unnamed: LED2.A, R10.2
unnamed: U7.29 ((IC1)PD4), U8.7 (ADDC)
unnamed: U7.30 ((XCK1)PD5), U8.8 (ADDB)
unnamed: U7.31 ((T1)PD6), U8.9 (ADDA)
unnamed: Q2.1 (G), R11.2, R12.1
unnamed: Q1.1 (G), R4.2, R5.1
unnamed: Q2.3 (G), Q2.6 (D), R8.2
unnamed: LED3.A, R21.2
unnamed: LED12.A, R75.2
unnamed: R74.1, U$4.1 (ANODE)
unnamed: Q11.3 (D), R75.1
unnamed: LED7.A, R52.2
unnamed: LED11.A, R71.2
unnamed: R54.1, U$1.1 (ANODE)
unnamed: TP2GOOD.1, U4.2 (PGOOD)
unnamed: LED9.A, R63.2
unnamed: Q9.3 (D), R63.1
unnamed: C11.1, U4.18 (DV/DT)
unnamed: Q4.1 (G), R22.2, R23.1
unnamed: Q4.4 (D), R20.1
unnamed: Q4.3 (G), Q4.6 (D), R17.2
unnamed: LED4.A, R28.2
unnamed: R65.2, R69.1, U13.14 (EN/UVLO)
unnamed: RILIM8.1, U13.17 (ILIM)
unnamed: TP7GOOD.1, U13.2 (PGOOD)
unnamed: C30.1, U13.18 (DV/DT)
unnamed: Q10.1 (G), R67.2, R68.1
unnamed: Q1.3 (G), Q1.6 (D), R1.2
unnamed: Q10.3 (G), Q10.6 (D), R64.2
unnamed: LED5.A, R42.2
unnamed: R47.2, R51.1, U9.14 (EN/UVLO)
unnamed: RILIM6.1, U9.17 (ILIM)
unnamed: TP5GOOD.1, U9.2 (PGOOD)
unnamed: C24.1, U9.18 (DV/DT)
unnamed: Q7.1 (G), R49.2, R50.1
unnamed: Q1.4 (D), R2.1
unnamed: Q7.3 (G), Q7.6 (D), R46.2
unnamed: LED6.A, R48.2
unnamed: R41.2, R45.1, U6.14 (EN/UVLO)
unnamed: RILIM5.1, U6.17 (ILIM)
unnamed: TP4GOOD.1, U6.2 (PGOOD)
unnamed: C21.1, U6.18 (DV/DT)
unnamed: Q6.1 (G), R43.2, R44.1
unnamed: Q5.4 (D), R27.1
unnamed: Q6.3 (G), Q6.6 (D), R40.2
unnamed: LED8.A, R56.2
unnamed: R27.2, R31.1, U5.14 (EN/UVLO)
unnamed: RILIM4.1, U5.17 (ILIM)
unnamed: TP3GOOD.1, U5.2 (PGOOD)
unnamed: C16.1, U5.18 (DV/DT)
unnamed: Q5.1 (G), R29.2, R30.1
unnamed: Q6.4 (D), R41.1
unnamed: Q5.3 (G), Q5.6 (D), R26.2
unnamed: LED10.A, R66.2
unnamed: R55.2, R59.1, U10.14 (EN/UVLO)
unnamed: RILIM7.1, U10.17 (ILIM)
unnamed: TP6GOOD.1, U10.2 (PGOOD)
unnamed: C26.1, U10.18 (DV/DT)
unnamed: Q8.1 (G), R57.2, R58.1
unnamed: TP56.1, U7.32 ((T2)PD7)
unnamed: Q8.3 (G), Q8.6 (D), R53.2
unnamed: C10.1, D3.2 (-), Q3.1 (G), R18.1
unnamed: U7.61 (PF0(ADC0)), U8.1 (COMM)
unnamed: Q7.4 (D), R47.1
unnamed: D3.1 (+), R14.1, R15.1, R16.1, R19.1, TP43.1
unnamed: Q10.4 (D), R65.1
unnamed: Q8.4 (D), R55.1
NUCLEAROPTION0: R16.2, U7.33 (PG0(WR))
NUCLEAROPTION1: R15.2, U7.34 (PG1(RD))
NUCLEAROPTION2: R14.2, U7.43 (PG2(ALE))
NUCLEAROPTION_OUT: CF1.P$15 (15), CF1.P$16 (16), Q3.3 (D), TP44.1
PB0: TP7.1, U7.10 ((SS)PB0)
PB1: TP8.1, U7.11 ((SCK)PB1)
PB2: TP9.1, U7.12 ((MOSI)PB2)
PB3: TP15.1, U7.13 ((MISO)PB3)
PB4: TP16.1, U7.14 ((OC0)PB4)
PB5: TP17.1, U7.15 ((OC1A)PB5)
PB6: TP18.1, U7.16 ((OC1B)PB6)
PB7: TP19.1, U7.17 ((OC2/OC1C)PB7)
PCB3_EN: R29.1, TP11.1, U7.47 ((AD4)PA4)
RXD0: Q11.1 (G), R72.2, U7.2 ((RXD/PDI)PE0)
RXD1: Q9.1 (G), R60.1, U7.27 ((RXD1/INT2)PD2)
TXD0: LED11.K, U7.3 ((TXD/PDO)PE1), U$2.2 (CATHODE)
TXD1: LED7.K, U7.28 ((TXD1/INT3)PD3), U$1.2 (CATHODE)
UART_FC_RX: CF1.P$23 (23), CF1.P$24 (24), R62.1, TP30.1
UART_FC_TX: CF1.P$25 (25), CF1.P$26 (26), TP31.1, U$3.2 (CATHODE)
UART_FC_VCC: C27.2, CF1.P$21 (21), CF1.P$22 (22), TP29.1, U$1.5 (VDD)
UART_LGR_RX: CF1.P$29 (29), CF1.P$30 (30), R73.1, TP33.1
UART_LGR_TX: CF1.P$31 (31), CF1.P$32 (32), TP34.1, U$4.2 (CATHODE)
UART_LGR_VCC: C31.2, CF1.P$27 (27), CF1.P$28 (28), TP32.1, U$2.5 (VDD)
V+: C3.+, C6.2, D1.2 (-), D2.2 (-), R7.1, U2.1 (VIN)
VBUS: C1.2, C7.2, C9.2, C14.2, C20.2, C22.2, C25.2, C29.2, CF1.P$1 (1), CF1.P$2 (2), CF1.P$3 (3), CF1.P$4 (4), CF1.P$5 (5), CF1.P$6 (6), CF1.P$7 (7), CF1.P$8 (8), D1.1 (+), Q1.2 (S), Q2.2 (S), Q4.2 (S), Q5.2 (S), Q6.2 (S), Q7.2 (S), Q8.2 (S), Q10.2 (S), R1.1, R8.1, R17.1, R26.1, R40.1, R46.1, R53.1, R64.1, U1.9 (IN), U1.10 (IN), U1.11 (IN), U1.12 (IN), U1.13 (IN), U3.9 (IN), U3.10 (IN), U3.11 (IN), U3.12 (IN), U3.13 (IN), U4.9 (IN), U4.10 (IN), U4.11 (IN), U4.12 (IN), U4.13 (IN), U5.9 (IN), U5.10 (IN), U5.11 (IN), U5.12 (IN), U5.13 (IN), U6.9 (IN), U6.10 (IN), U6.11 (IN), U6.12 (IN), U6.13 (IN), U9.9 (IN), U9.10 (IN), U9.11 (IN), U9.12 (IN), U9.13 (IN), U10.9 (IN), U10.10 (IN), U10.11 (IN), U10.12 (IN), U10.13 (IN), U13.9 (IN), U13.10 (IN), U13.11 (IN), U13.12 (IN), U13.13 (IN)
VCB0: CF2.P$1 (1), CF2.P$2 (2), CF2.P$3 (3), CF2.P$4 (4), R3.1, U1.4 (OUT), U1.5 (OUT), U1.6 (OUT), U1.7 (OUT), U1.8 (OUT)
VCB0_!FLT: R32.2, TP26.1, U1.20 (!FLT), U7.42 ((A15)PC7)
VCB0_EN: R4.1, TP14.1, U7.44 ((AD7)PA7)
VCB0_IMON: RIMON1.1, U1.19 (IMON), U8.11 (NO0\)
VCB1: CF2.P$5 (5), CF2.P$6 (6), CF2.P$7 (7), CF2.P$8 (8), R10.1, U3.4 (OUT), U3.5 (OUT), U3.6 (OUT), U3.7 (OUT), U3.8 (OUT)
VCB1_!FLT: R33.2, TP25.1, U3.20 (!FLT), U7.41 ((A14)PC6)
VCB1_EN: R11.1, TP13.1, U7.45 ((AD6)PA6)
VCB1_IMON: RIMON2.1, U3.19 (IMON), U8.12 (NO1)
VCB2: CF2.P$11 (11), CF2.P$12 (12), CF2.P$13 (13), CF2.P$14 (14), R21.1, U4.4 (OUT), U4.5 (OUT), U4.6 (OUT), U4.7 (OUT), U4.8 (OUT)
VCB2_!FLT: R34.2, TP24.1, U4.20 (!FLT), U7.40 ((A13)PC5)
VCB2_EN: R22.1, TP12.1, U7.46 ((AD5)PA5)
VCB2_IMON: RIMON3.1, U4.19 (IMON), U8.13 (NO2)
VCB3: CF2.P$15 (15), CF2.P$16 (16), CF2.P$17 (17), CF2.P$18 (18), R28.1, U5.4 (OUT), U5.5 (OUT), U5.6 (OUT), U5.7 (OUT), U5.8 (OUT)
VCB3_!FLT: R35.2, TP23.1, U5.20 (!FLT), U7.39 ((A12)PC4)
VCB3_IMON: RIMON4.1, U5.19 (IMON), U8.10 (NO3)
VCB4: CF2.P$21 (21), CF2.P$22 (22), CF2.P$23 (23), CF2.P$24 (24), R42.1, U6.4 (OUT), U6.5 (OUT), U6.6 (OUT), U6.7 (OUT), U6.8 (OUT)
VCB4_!FLT: R36.2, TP22.1, U6.20 (!FLT), U7.38 ((A11)PC3)
VCB4_EN: R43.1, TP10.1, U7.48 ((AD3)PA3)
VCB4_IMON: RIMON5.1, U6.19 (IMON), U8.15 (NO4)
VCB5: CF2.P$25 (25), CF2.P$26 (26), CF2.P$27 (27), CF2.P$28 (28), R48.1, U9.4 (OUT), U9.5 (OUT), U9.6 (OUT), U9.7 (OUT), U9.8 (OUT)
VCB5_!FLT: R37.2, TP21.1, U7.37 ((A10)PC2), U9.20 (!FLT)
VCB5_EN: R49.1, TP6.1, U7.49 ((AD2)PA2)
VCB5_IMON: RIMON6.1, U8.3 (NO5), U9.19 (IMON)
VCB6: CF2.P$31 (31), CF2.P$32 (32), CF2.P$33 (33), CF2.P$34 (34), R56.1, U10.4 (OUT), U10.5 (OUT), U10.6 (OUT), U10.7 (OUT), U10.8 (OUT)
VCB6_!FLT: R38.2, TP20.1, U7.36 ((A9)PC1), U10.20 (!FLT)
VCB6_EN: R57.1, TP3.1, U7.50 ((AD1)PA1)
VCB6_IMON: RIMON7.1, U8.16 (NO6), U10.19 (IMON)
VCB7: CF2.P$35 (35), CF2.P$36 (36), CF2.P$37 (37), CF2.P$38 (38), R66.1, U13.4 (OUT), U13.5 (OUT), U13.6 (OUT), U13.7 (OUT), U13.8 (OUT)
VCB7_!FLT: R39.2, TP45.1, U7.35 ((A8)PC0), U13.20 (!FLT)
VCB7_EN: R67.1, TP2.1, U7.51 ((AD0)PA0)
VCB7_IMON: RIMON8.1, U8.2 (NO7), U13.19 (IMON)
VSOL: CF1.P$9 (9), CF1.P$10 (10), CF1.P$11 (11), CF1.P$12 (12), CF1.P$13 (13), CF1.P$14 (14), D2.1 (+)

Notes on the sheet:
William Harrington, James Heath, Shan Quinney
LDO for System Controller (RH) Why are we using this LDO?
Main Power Bus
Battery bus
Solar bus
Power Control for: 1. LGR 2. FC 3. DxWiFi 4. ACS-RW 5. ACS-MAG 6. IMU 7. SDR-GPS
Set RILIM resistors to 47k which gives about 1.9A limit
dV/dt defaults to 12V/ms with no external capacitor. Otherwise use: C = 12uA/desired output slew rate (dV/dt)
RIMONmax = 3V divided by (ILIM x 52uA/A) with Vin(max) = 53V and ILIM = 1.9A, RIMON = 30k
ILIM = 89/RILIM (kOhms)
!FLT! will be low when a fault is detected
Set UVLO to 3.0V
UART0 TX (to LGR)
UART1 RX (from FC)
UART0 RX (from LGR)
UART1 TX (to FC)
VBC2
VBC3
VBC4
VBC5
VBC6
VBC7
Hard enabled when INH is tied to ground Connect GRD to analog ground plane
Select Pins OK?
"Nuclear Option" system-wide hard shutdown
Voltage Divider: Requires NUCLEAROPTION2 + NUCLEAROPTION1 + NUCLEAROPTION0 across this resistor (minus the diode turn-on voltage) to turn on the MOSFET
Schottky Diode: Forward V-drop 0.45V
RC time constant
8 MHz
DMN62D0U (Vishay) V(TH) min = 0.5V, V(TH) max = 1.0V
Assuming 3V at each pin: When all three pins are high the voltage at TP43 is 2.25V When two pins are high the voltage at TP43 is 1.5V When all three pins are high the voltage at TP43 is 0.75V
Look for TPs connected to GND!!!!!!
1.1
Pin 4 is a NC. Remove C4 from future layouts.

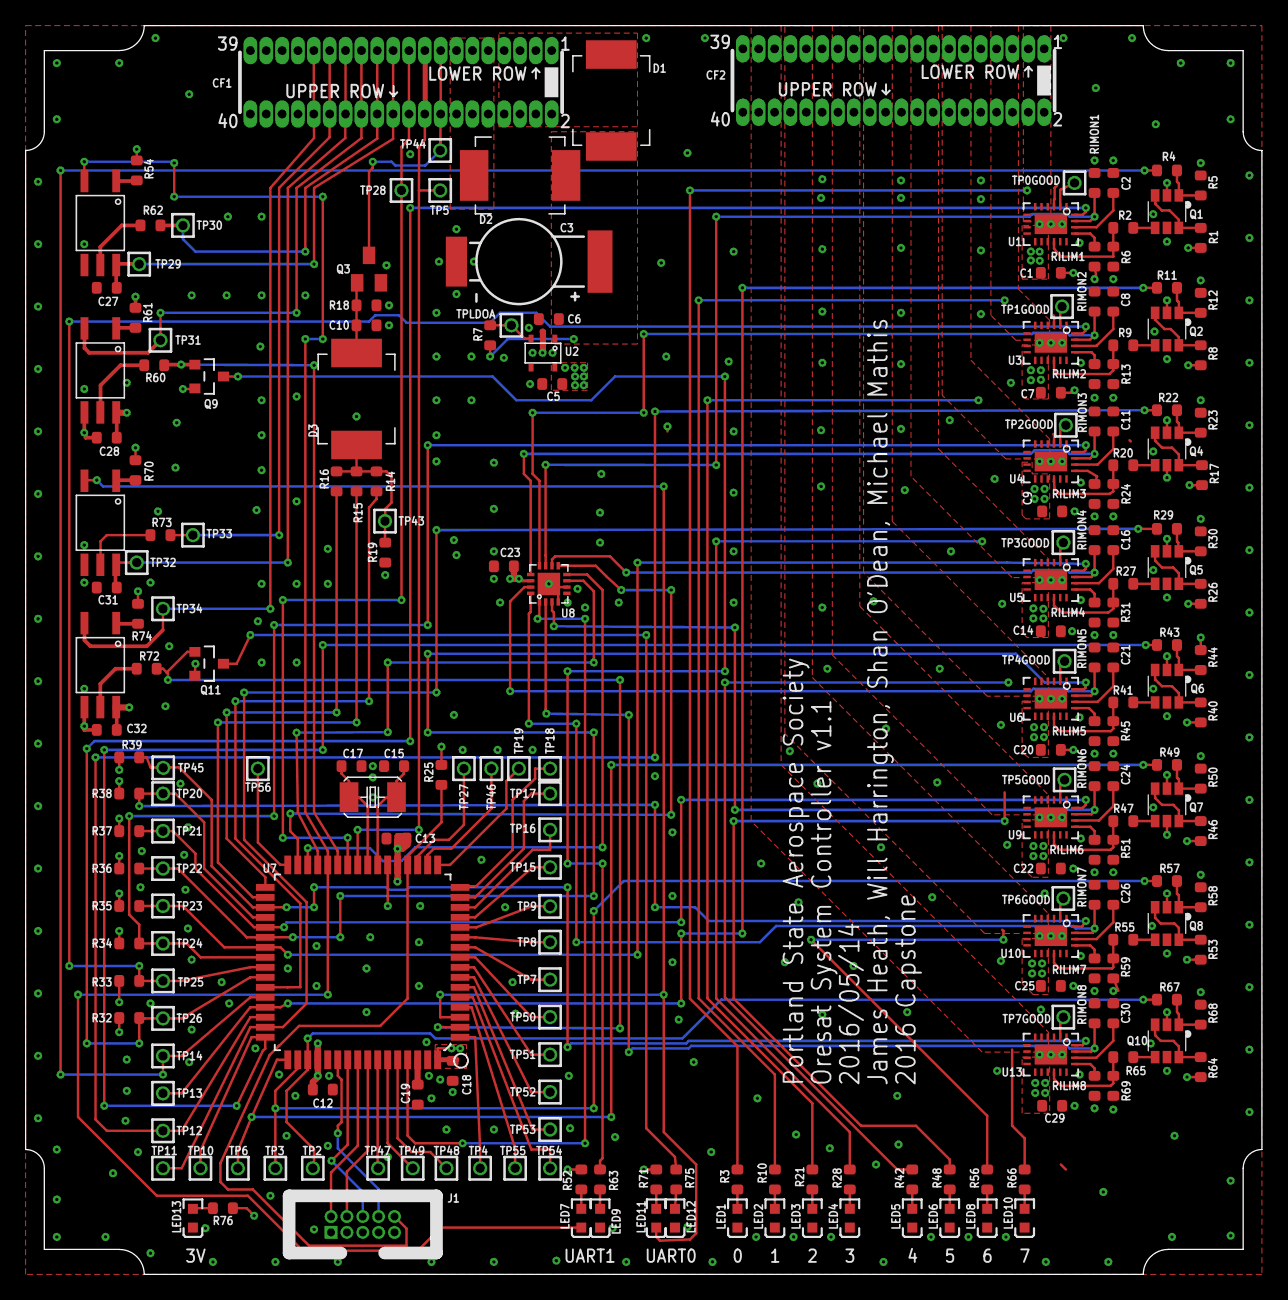
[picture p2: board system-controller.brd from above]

Board: 4 copper layers, 99.0 x 100.0 mm, 226 parts (0 on the bottom side), 168 nets.

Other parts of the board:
U$5: ORESAT-CARD-V0.3

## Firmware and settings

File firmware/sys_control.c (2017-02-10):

/*****************************************************
 * System Controller for ORESAT Sputnik C3 module    *
 * The system controller is designed to reset the    *
 * low gain radio and payload if a latch up event    *
 * is detected.					     *
 * This controller firmware resets a countdown timer *
 * whenever a 'G' is received by the uart. If a 'G'  *
 * isn't received in time, the timer interrupt will  *
 * run the reset_lgr routine. 			     *
 * Originally programmed by Michael Mathis	     *
 * Refactored and maintained by William Harrington   *
 *****************************************************/

#include <avr/io.h>
#include <util/delay.h>
//#define F_CPU 8000000UL add this to your util/delay.h to get rid of compiler warning

#include <avr/interrupt.h>
#include "uart.h"
#include "port.h"
#include "adc.h"
#include "i2c.h"
#include <stdlib.h>
#include "debug.h"
#include "timer.h"

/* uart configuration */
usart_config_t usart_cfg = {
    .module = UART0,
    .baud = 51, //9600
    .mode = MODE_8_BIT
};

/* timer configuration */
timer_cfg_t timer_cfg = {
    .clk_divider = 0x5,
    .compare_val = 0xFA0,
    .interrupt_mask = 0x10,
};

enum efuse {VCB0_EN = (uint8_t)'1',
    VCB1_EN,
    VCB2_EN,
    VCB3_EN,
    VCB4_EN,
    VCB5_EN,
    VCB6_EN,
    VCB7_EN
};

bool reset_lgr(void){
    //critical task, must be performed, disable interrupts
    cli();
    
    //Pull PORTA pins 0 and 1 down for 2 seconds then reset the timer count
    uint8_t i;
    for(i = 0; i < 2; i++){
        if(!toggle_pin(&PORTA, i, OFF)){
            return false;
        }
    }
    _delay_ms(2000);
    for(i = 0; i < 2; i++){
        if(!toggle_pin(&PORTA, i, ON)){
            return false;
        }
    }
    
    //reset the counter
    TCNT1 = 0x0000;
    
    //allow for interrupts again
    sei();
    
    return true;
}

bool start_periph(){
    return (gpio_init() &&
            usart_init(&usart_cfg) &&
            adc_init() &&
            i2c_init() &&
            timer_init(&timer_cfg));
}

int main (void){
#if DEBUG_UART_TX
    testTxUART();
#endif
#if DEBUG_ADC
    testADC();
#endif
#if DEBUG_MAIN
    unsigned char data = 'G';
#endif
    
    if(!start_periph()){
        trap(STAGE1);
    }
    sei(); //Enable global interrupts
    
    while (1) {
#if DEBUG_MAIN
        _delay_ms(500);
        if(!put_char(data)){
            trap(STAGE2);
        }
        toggle_pin(&PORTF, pin0, TOGGLE);
#endif
    }
    return 0;
}

ISR(TIMER1_COMPA_vect){
    //Timer 1 compare register A interrupt handler
    if(!reset_lgr()){
        trap(STAGE2);
    }
}

ISR(USART0_RX_vect){
    //UART receive interrupt handler
    unsigned char * data;
    get_char(data);
    if ((*data) == 'G'){		//Test against lgr's I'm alive signal
        TCNT1 = 0x0000;		//Reset timer count
    }
    switch(*data){			//Toggle port f pins
        case VCB0_EN:
            toggle_pin(&PORTA, pin7, TOGGLE);
            break;
        case VCB1_EN:
            toggle_pin(&PORTA, pin6, TOGGLE);
            break;
        case VCB2_EN:
            toggle_pin(&PORTA, pin5, TOGGLE);
            break;
        case VCB3_EN:
            toggle_pin(&PORTA, pin4, TOGGLE);
            break;
        case VCB4_EN:
            toggle_pin(&PORTA, pin3, TOGGLE);
            break;
        case VCB5_EN:
            toggle_pin(&PORTA, pin2, TOGGLE);
            break;
        case VCB6_EN:
            toggle_pin(&PORTA, pin1, TOGGLE);
            break;
        case VCB7_EN:
            toggle_pin(&PORTA, pin0, TOGGLE);
            break;
    }
    
    //Echo the RX data back for analysis
    put_char(*data);
}

//General interrupt handler, do nothing if we get stray interrupts
EMPTY_INTERRUPT(BADISR_vect);

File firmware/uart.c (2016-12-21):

/*
 UART driver for ATMega128
 Programmed by William Harrington
 */

#include "uart.h"

static usart_config_t activeCfg;

static bool uart_init(usart_config_t * cfg){
    activeCfg = *cfg;
    switch(cfg->module){
        case UART0:
            UBRR0H = (cfg->baud >> 8) & 0xFF;
            UBRR0L = cfg->baud & 0xFF;
            return (setBit(&UCSR0B, RXEN) &&
                    setBit(&UCSR0B, TXEN) &&
                    setBit(&UCSR0C, USBS) &&
                    setBit(&UCSR0C, UCSZ0) &&
                    UBRR0H == ((cfg->baud >> 8) & 0xFF) &&
                    UBRR0L == ((cfg->baud) & 0xFF));
        case UART1:
            UBRR1H = (cfg->baud >> 8) & 0xFF;
            UBRR1L = cfg->baud & 0xFF;
            return (setBit(&UCSR1B, RXEN) &&
                    setBit(&UCSR1B, TXEN) &&
                    setBit(&UCSR1C, USBS) &&
                    setBit(&UCSR1C, UCSZ0) &&
                    UBRR1H == ((cfg->baud >> 8) & 0xFF) &&
                    UBRR1L == ((cfg->baud) & 0xFF));
        case USART0:
            UBRR0H = (cfg->baud >> 8) & 0xFF;
            UBRR0L = cfg->baud & 0xFF;
            return (setBit(&UCSR0B, RXEN) &&
                    setBit(&UCSR0B, TXEN) &&
                    setBit(&UCSR0C, USBS) &&
                    setBit(&UCSR0C, UCSZ0) &&
                    setBit(&UCSR0C, 6) &&
                    UBRR0H == ((cfg->baud >> 8) & 0xFF) &&
                    UBRR0L == ((cfg->baud) & 0xFF));
        case USART1:
            UBRR1H = (cfg->baud >> 8) & 0xFF;
            UBRR1L = cfg->baud & 0xFF;
            return (setBit(&UCSR1B, RXEN) &&
                    setBit(&UCSR1B, TXEN) &&
                    setBit(&UCSR1C, USBS) &&
                    setBit(&UCSR1C, UCSZ0) &&
                    setBit(&UCSR1C, 6) &&
                    UBRR1H == ((cfg->baud >> 8) & 0xFF) &&
                    UBRR1L == ((cfg->baud) & 0xFF));
        default:
            return false;
    }
}

bool usart_init(usart_config_t * cfg){
    return uart_init(cfg);
}

bool put_char(unsigned char ch){
    usart_module_t module = activeCfg.module;
    usart_mode_t mode = activeCfg.mode;
    if(module == UART0 || module == USART0){
        if(mode == MODE_8_BIT){
            while (!(UCSR0A & (1<<UDRE)));
            UDR0 = ch;
            while(!((UCSR0A >> 6) & 0x1));
            return true;
        }
        else if(mode == MODE_9_BIT){
            return false;
        }
    }
    else if(module == UART1 || module == USART1){
        if(mode == MODE_8_BIT){
            while (!(UCSR1A & (1<<UDRE)));
            UDR1 = ch;
            while(!((UCSR1A >> 6) & 0x1));
            return true;
        }
        else if(mode == MODE_9_BIT){
            return false;
        }
    }
    return false;
}

bool get_char(unsigned char * ch){
    usart_module_t module = activeCfg.module;
    usart_mode_t mode = activeCfg.mode;
    if(module == UART0 || module == USART0){
        if(mode == MODE_8_BIT){
            while(!(UCSR0A & (1<<RXC)));
            *ch = UDR0;
            return (bool)((UCSR0A >> 7) & 0x1);
        }
        else if(mode == MODE_9_BIT){
            return false;
        }
    }
    else if(module == UART1 || module == USART1){
        if(mode == MODE_8_BIT){
            while(!(UCSR1A & (1<<RXC)));
            *ch = UDR1;
            return (bool)((UCSR1A >> 7) & 0x1);
        }
        else if(mode == MODE_9_BIT){
            return false;
        }
    }
    return false;
}

bool println(char * string){
    while(*string != '\0'){
        if(!put_char(*string++)){
            return false;
        }
    }
    return true;
}

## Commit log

2016-02-27 Split schematic, added SPI cache symbol/fp, updated LL design
    [sputnik_prototype_SysController.brd, sputnik_prototype_SysController.sch]
2016-02-28 Added GPIOs and other updates on SysCon sch. Updated SPI cache footprint
    [sputnik_prototype_SysController.brd, sputnik_prototype_SysController.sch]
2016-02-28 Added super cap and LDO holding place
    [sputnik_prototype_SysController.brd, sputnik_prototype_SysController.sch]
2016-02-28 Added LNA LDO footprint and circuitry
    [sputnik_prototype_SysController.sch]
2016-02-28 Updated to do list
    [sputnik_prototype_SysController.sch]
2016-02-29 Added rad-hard model LDO
    [sputnik_prototype_SysController.brd, sputnik_prototype_SysController.sch]
2016-02-29 Fixed to do list
    [sputnik_prototype_SysController.sch]
2016-03-01 Updated to do lists
    [sputnik_prototype_SysController.sch]
2016-03-03 Added optocoupler datasheet and into the schematic
    [sputnik_prototype_SysController.brd, sputnik_prototype_SysController.sch]
2016-03-03 added attributes, replaced atmega footprint with correct version, replaced resonator with xtal
    [sputnik_prototype_SysController.brd, sputnik_prototype_SysController.sch]
2016-03-04 Got rid of SysCon LDO, fixed Optoisolator symbol
    [sputnik_prototype_SysController.brd, sputnik_prototype_SysController.sch]
2016-03-05 Fixed OIs, fixed SysCon LDO, replaced SPI cache
    [sputnik_prototype_SysController.brd, sputnik_prototype_SysController.sch]
2016-03-05 Had to fix to do again because I'm a dumbass
    [sputnik_prototype_SysController.sch]
2016-03-19 Added the diodes and fixed the Crystal
    [sputnik_prototype_SysController.sch]
2016-03-19 added headers to power supply
    [sputnik_prototype_SysController.brd, sputnik_prototype_SysController.sch]
2016-03-23 Clean up on system controller board. Added 40 pin connector, board outline, ground planes. Killed all old spurious signals. Removed unecessary connectors. Still need to find small power controllers t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
    [sputnik_prototype_SysController.brd, sputnik_prototype_SysController.sch]
2016-03-28 Newest outline of SC board, added secondary connector because we're going to need it for the output.
    [sputnik_prototype_SysController.brd, sputnik_prototype_SysController.sch]
2016-04-01 Added the bare switch and deleted some text
    [sputnik_prototype_SysController.sch]
2016-04-03 worked on the switch schematic
    [sputnik_prototype_SysController.brd, sputnik_prototype_SysController.sch]
2016-04-03 A few more changes
    [sputnik_prototype_SysController.brd, sputnik_prototype_SysController.sch]
2016-04-03 latest changes
    [sputnik_prototype_SysController.brd, sputnik_prototype_SysController.sch]
2016-04-03 added a pull up resistor to FLT
    [sputnik_prototype_SysController.brd, sputnik_prototype_SysController.sch]
2016-04-04 added the mux to the schematic
    [sputnik_prototype_SysController.brd, sputnik_prototype_SysController.sch]
2016-04-04 added the updated mux to the schematic
    [sputnik_prototype_SysController.brd, sputnik_prototype_SysController.sch]
2016-04-07 Added DNP LEDs and MOSFET drives to UARTs. Fixed TPS circuits with SOT-32-6 N/P MOSFET pair, which worked out nicely. Added another TPS to flesh it out, make sure it wasn't totally stupid. Added more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
    [sputnik_prototype_SysController.brd, sputnik_prototype_SysController.sch]
2016-04-07 renamed boards
    [system-controller.brd, system-controller.sch]
2016-04-08 made changes to schematic: removed 16:1 mux, added 8:1 mux, configured remaining 8 eFuses, other
    [system-controller.brd, system-controller.sch]
2016-04-09 added the remaining attribute info, fixed the footprint for the optoisolators
    [system-controller.brd, system-controller.sch]
2016-04-10 Added a rough draft Hardware (analog) Watchdog circuit, added the voltage divider values for the UVLO pin on the eFuse
    [system-controller.brd, system-controller.sch]
2016-04-10 added the MOSFET to the analog watchdog circuit
    [system-controller.brd, system-controller.sch]
2016-04-10 Fixed nuclear option. Fixed ERCs. Found ERCs in ATMEGAS128, so broke that out of the default ATMEL library from CADSOFT and made our own (now in the oresat-eagle-libraries repo). Replaced test points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
    [system-controller.brd, system-controller.sch]
2016-04-12 added the remaining test points
    [system-controller.brd, system-controller.sch]
2016-04-16 working on board layout. Have everything organized in in general location. Working on routing.
    [system-controller.brd, system-controller.sch]
2016-04-18 Pushing newest changes to the board layout
    [system-controller.brd, system-controller.sch]
2016-04-19 Design review with Shan and Andrew. Cleaned up polygons and polygon ranks. Used correct DRC rules.
    [system-controller.brd]
2016-04-25 latetest changes pushed
    [system-controller.brd, system-controller.sch]
2016-04-26 latest changes... thicker polys, moved some traces, more...
    [system-controller.brd, system-controller.sch]
2016-04-26 added the RIMON resister value and dV/dt cap value
    [system-controller.brd, system-controller.sch]
2016-04-26 latest minor changes
    [system-controller.brd, system-controller.sch]
2016-04-27 made polygons wider and changed physical layout of them. Also, reduced space between traces
    [system-controller.brd, system-controller.sch]
2016-04-27 latest updates added
    [system-controller.brd, system-controller.sch]
2016-04-28 Initial sys controller firmware. Reset a countdown whenever a 'G' is received by the uart if a 'G' isn't received in time, the timer interrupt will run the reset_lgr routine
    [sys_control.c, uart.c]
2016-04-29 newest changes
    [system-controller.brd, system-controller.sch]
2016-04-30 final changes pushed for the day: change to optical isolation circuitry and board fixes due to this
    [system-controller.brd, system-controller.sch]
2016-04-30 I lied. 1 more
    [system-controller.brd]
2016-04-30 Update PartsSelection.md
    Made some updates. Finished up Atmel part, but still needs the reasons behind it. Worked on the opto-isolator part. A lot of these seem to be missing eagle reference numbers on the schematic and board??
2016-04-30 Better layout for bypass caps ner AVR. Some cleanup on routing. Changed power domain indicators to DNP.
    [system-controller.brd, system-controller.sch]
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2016-05-06 Added the BOM to the docs folder
    [BOM_SC.xls]
2016-05-09 Made some additions to the PartSelection document and fixed some issues on the BOM
    [BOM_SC.xls]
2016-05-09 A few more quick changes
    [BOM_SC.xls]
2016-05-10 Some changes to the format of the PartsSelection doc and a few changes to the BOM
    [BOM_SC.xls]
2016-05-10 Board cleanup.
    [system-controller.brd]
2016-05-10 Added names to missing parts and updated the BOM and Parts Selection doc accordingly
    [system-controller.brd, system-controller.sch]
2016-05-11 More board cleanup!
    [system-controller.brd, system-controller.sch]
2016-05-13 Lots of board cleanup. Improved packages for ATMEGA, analog switch, and TPS. Re-did power polygons to tighten up the layout. Straightened wires because OCD, fixed DRCs.
    [system-controller.brd, system-controller.sch]
2016-05-14 Added 3V LED for power. Fixed a DRC error which wasn't caught earlier? How'd that happen? Also pushing gerbers, since some folks don't have EAGLE.
    [system-controller.brd, system-controller.sch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]
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2016-05-17 Updating resitor and capacitor names
    [BOM_SC.xls, system-controller.brd, system-controller.sch]
2016-05-17 added the 0 Ohm resistors R60 and R72
    [BOM_SC.xls]
2016-05-23 added missing datasheets
    [system-controller.brd, system-controller.sch]
2016-06-01 added to the BOM
    [BOM_SC.xls]
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2016-06-08 Update README.md
    Added image of the SC board to the Readme file
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2016-07-12 Fixed some of the remaining issues such as JTAG layout and schematic, 0 ohm resistors, etc. Check the issue section on the git for more info
    [system-controller.brd, system-controller.sch]
2016-07-19 fixed reference designator and origin on optoisolator
    [system-controller.brd, system-controller.sch]
2016-07-20 Fixed opto-isolator symbol with proper labels
    [system-controller.brd, system-controller.sch]
2016-08-21 Refactoring system controller firmware
    1. Create toggle pin function meant for changing logic level on pin
    2. Created io direction setter function
    3. Replaced bit banging with calls to new functions (see above).
    4. F_CPU not set in util/delay.h see note in code
    [sys_control.c]
2016-08-23 fixed logic in toggle_pin and set_io_direction functions
    [port.c]
2016-09-03 i2c driver, fixed defines in adc, added adc and i2c to sys_control.c
    [adc.c, i2c.c, sys_control.c]
2016-09-03 call to i2c_init added to sys_control.c, note that this code is untested but compiles
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2016-09-06 corrected logic on argument checking in port functions
    [port.c]
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2016-12-11 1. Debugged lots of my new code that I committed prior 2. Added more debug infrastructure 3. Corrected mistakes in some init procedures 4. Made timer setup its own implementation and header file
    [debug.c, port.c, sys_control.c]
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
